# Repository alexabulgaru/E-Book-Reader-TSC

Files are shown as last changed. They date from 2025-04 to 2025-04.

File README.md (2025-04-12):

# E-Book-Reader-TSC - Bulgaru Alexandra 331CD

## Diagrama bloc

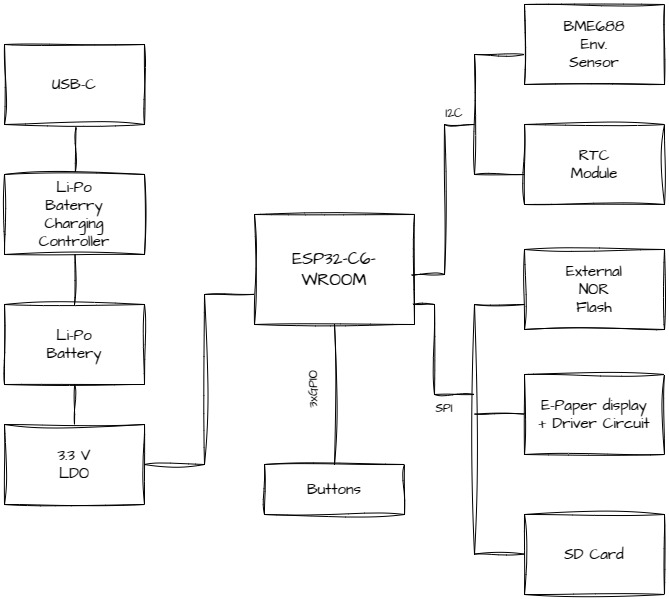
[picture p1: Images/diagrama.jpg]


## Bill Of Materials (BOM)
| Componenta | Achizitie | Datasheet |
| --- | --- | --- |
| PFMF.050.1 | [Cumpara](https://ro.mouser.com/ProductDetail/Schurter/PFMF.050.2?qs=1auRipcfynCums5v1iucSA%3D%3D) |  [Datasheet](https://ro.mouser.com/datasheet/2/358/typ_PFMF-1275918.pdf) |
| USB4110-GF-A | [Cumpara](https://ro.mouser.com/ProductDetail/GCT/USB4110-GF-A?qs=KUoIvG%2F9IlYiZvIXQjyJeA%3D%3D) | [Datasheet](https://ro.mouser.com/datasheet/2/837/GCT_USB4110_Product_Drawing___20k_cycles-3455479.pdf) |
| USBLC6-2SC6Y | [Cumpara](https://ro.mouser.com/ProductDetail/STMicroelectronics/USBLC6-2SC6Y?qs=gNDSiZmRJS%2FOgDexvXkdow%3D%3D) | [Datasheet](https://ro.mouser.com/datasheet/2/389/usblc6_2sc6y-1852505.pdf) |
| SD0805S020S1R0 | [Cumpara](https://ro.mouser.com/ProductDetail/KYOCERA-AVX/SD0805S020S1R0?qs=jCA%252BPfw4LHbpkAoSnwrdjw%3D%3D) | [Datasheet](https://ro.mouser.com/datasheet/2/40/schottky-3165252.pdf) |
| DMG2305UX-7 | [Cumpara](https://ro.mouser.com/ProductDetail/Diodes-Incorporated/DMG2305UX-7?qs=L1DZKBg7t5F%2FNBHrjfxC%252Bg%3D%3D) | [Datasheet](https://www.diodes.com/assets/Datasheets/DMG2305UX.pdf) |
| XC6220A331MR-G | [Cumpara](https://ro.mouser.com/ProductDetail/Torex-Semiconductor/XC6220A331MR-G?qs=AsjdqWjXhJ8ZSWznL1J0gg%3D%3D) | [Datasheet](https://ro.mouser.com/datasheet/2/760/xc6220-3371556.pdf) |
| Condensator 100 uF TANT | [Cumpara](https://ro.mouser.com/ProductDetail/KYOCERA-AVX/TAJW107M010RNJ?qs=Wtp%252Bf%2FAeVqIH8v1VxV%252B1Rg%3D%3D) | [Datasheet](https://ro.mouser.com/datasheet/2/40/TAJ-3165264.pdf) |
| 112A-TAAR-R03_ATTEND | [Cumpara](https://www.digikey.ro/en/products/detail/attend-technology/112A-TAAR-R03/17633923) | [Datasheet](https://www.attend.com.tw/data/download/file/112A-TAAR-R03_Spec.pdf)
| ESP32-C6-WROOM-1-N8 | [Cumpara](https://ro.mouser.com/ProductDetail/Espressif-Systems/ESP32-C6-WROOM-1-N8?qs=8Wlm6%252BaMh8ST02Gmwp74cw%3D%3D) | [Datasheet](https://ro.mouser.com/datasheet/2/891/Espressif_ESP32_C6_WROOM_1__Datasheet_V0_1_PRELIMI-3239987.pdf) |
| MCP73831 | [Cumpara](https://ro.mouser.com/ProductDetail/Microchip-Technology/MCP73831T-2ACI-OT?qs=yUQqVecv4qvbBQBGbHx0Mw%3D%3D) | [Datasheet](https://ro.mouser.com/datasheet/2/268/MCP73831_Family_Data_Sheet_DS20001984H-3441711.pdf) |
| CHG_LED | [Cumpara](https://store.comet.srl.ro/Catalogue/Product/40478/) | [Datasheet](https://www.snapeda.com/parts/KP-1608SURCK/Kingbright/datasheet/) |
| SI1308EDL-T1-GE3 | [Cumpara](https://ro.mouser.com/ProductDetail/Vishay-Semiconductors/SI1308EDL-T1-GE3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) | [Datasheet](https://www.vishay.com/doc?63399) |
| MBR0530 | [Cumpara](https://ro.mouser.com/ProductDetail/Micro-Commercial-Components-MCC/MBR0530-T?qs=9VyI4qLX4NTSXkb9ynzJnA%3D%3D) | [Datasheet](https://ro.mouser.com/datasheet/2/258/mcc_mbr0520~mbr0560sod123-1179695.pdf) |
| Bobina | [Cumpara](https://ro.mouser.com/ProductDetail/Wurth-Elektronik/744043680?qs=PGXP4M47uW6VkZq%252BkzjrHA%3D%3D) | [Datasheet](https://www.we-online.com/components/products/datasheet/744043680.pdf) |
| FH34SRJ-24S-0.5SH_99_ | [Cumpara](https://ro.mouser.com/ProductDetail/Hirose-Connector/FH34SRJ-24S-0.5SH99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) | [Datasheet](https://ro.mouser.com/datasheet/2/185/FH34SRJ_24S_0_5SH_99__CL0580_1255_6_99_2DDrawing_0-1615044.pdf) |
| BME688 | [Cumpara](https://ro.mouser.com/ProductDetail/Bosch-Sensortec/BME688?qs=IS%252B4QmGtzzqQoVDscqwx3A%3D%3D) | [Datasheet](https://ro.mouser.com/datasheet/2/783/bst_bme688_fl000-2307034.pdf) |
| BD5229G-TR | [Cumpara](https://ro.mouser.com/ProductDetail/ROHM-Semiconductor/BD5229G-TR?qs=4kLU8WoGk0vvnhrrYwdszw%3D%3D) | [Datasheet](https://fscdn.rohm.com/en/products/databook/datasheet/ic/power/voltage_detector/bd52xxg-e.pdf) |
| Buton adaptat | [Cumpara](https://ro.mouser.com/ProductDetail/CK/KMR221GULCLFS?qs=u2NJ%252B70r0goBXaNk7IrU0Q%3D%3D) | [Datasheet](https://www.ckswitches.com/media/1479/kmr2.pdf) |
| MAX17048G+T10 | [Cumpara](https://ro.mouser.com/ProductDetail/Analog-Devices-Maxim-Integrated/MAX17048G%2bT10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) | [Datasheet](https://ro.mouser.com/datasheet/2/609/MAX17048_MAX17049-3469099.pdf) |
| W25Q512JVEIQ | [Cumpara](https://ro.mouser.com/ProductDetail/Winbond/W25Q512JVEIQ?qs=l7cgNqFNU1jw6svr3at6tA%3D%3D) | [Datasheet](https://ro.mouser.com/datasheet/2/949/Winbond_W25Q512JV_Datasheet-3240039.pdf) |
| PGB1010603MR | [Cumpara](https://ro.mouser.com/ProductDetail/Littelfuse/PGB1010603MRHF?qs=KvZd0dN2Zg%2FuIq6icj%252BGKA%3D%3D) | [Datasheet](https://www.littelfuse.com/media?itemid=8a337998-d54d-466b-be4e-dc5bcd1f9321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) |
| QWIIC_RIGHT_ANGLE | [Cumpara](https://ro.mouser.com/ProductDetail/GCT/USB4110-GF-A?qs=KUoIvG%2F9IlYiZvIXQjyJeA%3D%3D) | [Datasheet](https://ro.mouser.com/datasheet/2/837/GCT_USB4110_Product_Drawing___20k_cycles-3455479.pdf) |
| DS3231SN# | [Cumpara](https://ro.mouser.com/ProductDetail/Analog-Devices-Maxim-Integrated/DS3231SN?qs=ffX8NcjNb2RmKAb9wAk9Ug%3D%3D) | [Datasheet](https://ro.mouser.com/datasheet/2/609/DS3231-3421123.pdf) |
| CPH3225A C10_SUPERCAP | [Cumpara](https://ro.mouser.com/ProductDetail/Seiko-Semiconductors/CPH3225A?qs=3etwrb1wR%252BhUOph6lAO7eg%3D%3D) | [Datasheet](https://ro.mouser.com/datasheet/2/360/Seiko_Instruments_MicroBattery_E_20230330_2024Jan_-3561061.pdf) |
| Condensator 100nF | [Cumpara](https://ro.mouser.com/ProductDetail/KYOCERA-AVX/06033G104ZAT2A?qs=NXubJDmysXJMPmHfVo6Z%252BA%3D%3D) | [Datasheet](https://ro.mouser.com/datasheet/2/40/KGM_Y5V-3223189.pdf) |
| Condensator 4.7uF | [Cumpara](https://ro.mouser.com/ProductDetail/KYOCERA-AVX/0402ZD475MAT2A?qs=NBFAU1oqP4W4U2PCPHI0sg%3D%3D) | [Datasheet](https://ro.mouser.com/datasheet/2/40/cx5r_KGM-3223198.pdf) |
| Condensator 10uF | [Cumpara](https://ro.mouser.com/ProductDetail/Samsung-Electro-Mechanics/CL10A106KQ8NNNL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) | [Datasheet](https://ro.mouser.com/datasheet/2/585/MLCC-1837944.pdf) |
| Condensator 1uF/50V | [Cumpara](https://ro.mouser.com/ProductDetail/KYOCERA-AVX/06035D105MAT2A?qs=k4kUdCzLgS5%252BURKe1SOIeQ%3D%3D) | [Datasheet](https://ro.mouser.com/datasheet/2/40/cx5r_KGM-3223198.pdf) |
| Rezistenta 10K | [Cumpara](https://ro.mouser.com/ProductDetail/Vishay-Beyschlag/MCS0402MD1002BE000?qs=17u8i%2FzlE8%2F9BrAaXkMk1w%3D%3D) | [Datasheet](https://www.vishay.com/doc?28952) |
| Rezistenta 200 | [Cumpara](https://ro.mouser.com/ProductDetail/Vishay-Beyschlag/MCS0402MD2000BE100?qs=3SvaY9RawMJNVte4F12%252BZQ%3D%3D) | [Datasheet](https://www.vishay.com/doc?28952) |
| Rezistenta 100K | [Cumpara](https://ro.mouser.com/ProductDetail/Vishay-Beyschlag/MCT0603PD1003DP500?qs=5aG0NVq1C4wWAn8Ei3OpZA%3D%3D) | [Datasheet](https://www.vishay.com/doc?28916) |
| Rezistenta 2.2 | [Cumpara](https://ro.mouser.com/ProductDetail/SEI-Stackpole/RMCF0402FT2R20?qs=IPgv5n7u5QbBgyl0jwhwsA%3D%3D) | [Datasheet](https://ro.mouser.com/datasheet/2/385/SEI_RMCF_RMCP-3077565.pdf) |
| Rezistenta 5K1| [Cumpara](https://www.venkel.com/part/TFCR0603-16W-K-5690FT) | [Datasheet](https://data.venkel.com/documents/tfcr-series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.) |
| Rezistenta 2K | [Cumpara](https://ro.mouser.com/ProductDetail/Vishay-Beyschlag/MCS04020C2001FE000?qs=wTZ%2FFzl837YG0wIkZJJOwQ%3D%3D) | [Datasheet](https://www.vishay.com/doc?28705) |
| Rezistenta 0.47 | [Cumpara](https://ro.mouser.com/ProductDetail/SEI-Stackpole/CSR0402JKR470?qs=IPgv5n7u5QawIB6nBEt8wA%3D%3D) | [Datasheet](https://ro.mouser.com/datasheet/2/385/SEI_CSR_CSRN-3077593.pdf) |
| Rezistenta 15 | [Cumpara](https://ro.mouser.com/ProductDetail/YAGEO/RT0402FRE0715RL?qs=BXCcY9r%252B08DFFpLSkPOIqQ%3D%3D) | [Datasheet](https://ro.mouser.com/datasheet/2/447/PYu_RT_1_to_0_01_RoHS_L_15-3461507.pdf) |
| SJ | [Cumpara](https://grabcad.com/library/solder-jumpers-1) | [Datasheet](https://docs.rs-online.com/6fae/A700000010766261.pdf)

## Functionalitatea Hardware
#### Alimentare & Baterie:
USB-C furnizeaza 5 V, intra in controllerul de incarcare Li-Po si LDO-ul de 3.3 V. Acest 3.3 V alimenteaza microcontrolerul (ESP32-C6), senzorii si perifericele. Bateria Li-Po asigura functionarea cand nu este disponibila o sursa USB.

Microcontrolerul (ESP32-C6) ruleaza firmware-ul, se conecteaza la retea (Wi-Fi 6, BLE), citeste senzorii interni (BME688, DS3231) si scrie/afiseaza pe ecranul E-Paper. Poate salva date sau citi fisiere din memoria externa Flash NOR sau de pe cardul SD.

#### Senzori & RTC:
BME688 (temperatura, umiditate, presiune, compusi volatili) si DS3231 (timp real) sunt pe magistrala I2C, astfel incat datele sunt preluate usor si prelucrate.

#### Afisaj E-Paper:
Se actualizeaza prin magistrala SPI; microcontrolerul trimite datele necesare prin pinul EPD_CS (chip select), EPD_DC (command/data), EPD_RST, iar afisajul confirma starea prin EPD_BUSY.

#### Extensii:
Qwiic / Stemma QT ofera posibilitatea de a conecta senzori suplimentari pe magistrala I2C; exista si un slot SD.

## Pini ESP32-C6
| Nume | GPIO / Pin | Functie | Descriere |
|---|---|---|---|
| **3V3** | 3V3 | Sursa principala de 3.3V | Asigura alimentarea necesara functionarii ESP32-C6 si a componentelor logice de pe placa |
| **EN (Reset)**  | EN | Activare/Dezactivare microcontroler | Controleaza alimentarea interna a modulului ESP32-C6; un impuls LOW poate reseta intregul sistem |
| **USB_D-** | IO12 | Linia negativa pentru USB | Utilizata in transferul de date prin protocol USB 2.0, in pereche diferentiala cu USB_D+ |
| **USB_D+** | IO13 | Linia pozitiva pentru USB | Utilizata in transferul de date prin protocol USB 2.0, in pereche diferentiala cu USB_D- |
| **Buton Boot**  | IO9 | Intrare in modul bootloader | Se conecteaza la masa pentru a forta incarcarea bootloader-ului ESP32-C6 (flash/programare firmware) |
| **Buton Change**| IO15 | Comutare mod de operare | Poate fi configurat in firmware pentru a schimba starea aplicatiei sau diverse moduri de functionare |
| **TX (UART)** | TXD0 / GPIO16 | Emisie seriala (UART) | Trimite date catre un terminal serial sau adaptor USB-serial, folosit pentru debug sau comunicatie |
| **RX (UART)** | RXD0 / GPIO17 | Receptie seriala (UART) | Primeste date de la un terminal serial sau adaptor USB-serial, folosit pentru debug sau comunicatie |
| **SCK (SPI)** | IO6 | Ceas SPI pentru transfer de date | Genereaza impulsurile de sincronizare pentru toate dispozitivele conectate la magistrala SPI |
| **MOSI (SPI)**  | IO7 | Linie de date catre dispozitive SPI (Master Out)| Transmite informatii de la microcontroler catre NOR Flash, card SD si ecran E-Paper |
| **MISO (SPI)**  | IO2 | Linie de date de la dispozitive SPI (Master In) | Receptioneaza informatii de la card SD, E-Paper si alte periferice SPI |
| **FLASH_CS** | IO11 | Selectare chip pentru memoria NOR Flash | Activeaza NOR Flash atunci cand se lucreaza cu acesta pe magistrala SPI |
| **EPD_CS** | IO10 | Selectare chip pentru E-Paper | Activeaza modulul E-Paper pe magistrala SPI in timpul transferului de date |
| **EPD_DC** | IO5 | Diferentiere comanda/date pentru E-Paper | Indica daca informatia transmisa pe SPI reprezinta instructiuni de control sau date de afisare |
| **EPD_RST** | IO23 | Reset extern E-Paper | Permite repornirea hardware a modulului E-Paper in cazul in care este necesar |
| **EPD_BUSY** | IO3 | Semnal de ocupare E-Paper | Avertizeaza microcontrolerul ca E-Paper este in curs de actualizare si nu poate primi alte comenzi |
| **SDA (I2C)** | IO21 | Linie de date I2C | Utilizata pentru comunicatia bidirectionala cu RTC DS3231, senzor BME688 si conector Qwiic/Stemma QT |
| **SCL (I2C)** | IO22 | Linie de ceas I2C | Sincronizeaza toate transferurile de pe magistrala I2C, inclusiv cu RTC, senzori si module de extensie |
| **SS_SD** | IO4 | Chip Select pentru card SD (SPI) | Stabileste cand cardul SD este activ pe magistrala SPI, prevenind conflicte cu alte dispozitive |
| **I2C_PW** | IO19 | Control alimentare senzori I2C | Poate porni sau opri tensiunea pentru senzorii conectati la magistrala I2C, contribuind la economisirea energiei |
| **EPD_3V3_C** | IO20 | Alimentare 3.3V dedicata E-Paper | Linie separata de 3.3V pentru a alimenta in mod specific modulul E-Paper si pentru a asigura stabilitatea semnalelor |
| **32KHZ** | IO1 | Linie semnal 32 kHz | Frecventa de ceas folosita de modulul RTC sau alte circuite care necesita un clock de 32 kHz |
| **INT_RTC** | IO0 | Intrerupere de la RTC DS3231 | Poate trezi ESP32-C6 din mod sleep sau poate semnala evenimente programate in RTC |
| **RTC_RST** | IO18 | Reset extern RTC | Linie pentru resetarea manuala a ceasului de timp real in situatii speciale |

## Estimare consum

| Componenta | Consum Activ (aprox) | Consum Sleep (aprox) | Observatii |
|---|---|---|---|
| ESP32-C6 | ~80–100 mA (Wi-Fi) | ~10–20 µA (DeepSleep)| Principalul consumator; Wi-Fi creste semnificativ consumul in mod activ |
| Senzor BME688 | ~2 mA in masurare | <1 µA in standby | Majoritatea timpului poate fi oprit sau in standby |
| RTC DS3231 | ~150–200 µA | ~3 µA in mod backup  | Funcioneaza permanent, dar consuma relativ putin |
| NOR Flash (SPI)  | ~10–30 mA | ~1 µA (Deep PwrDown) | Activ doar la operatiile de citire/scriere |
| E-Paper Display  | ~20–50 mA la refresh | ~0 µA in pasiv | Odata afisat, nu mai consuma energie pentru mentinerea imaginii |
| LDO + pasive | ~10–50 µA | n/a | Curent de repaus al regulatorului si mici consumuri auxiliare (rezistente, LED-uri etc.) |

## Etape implementare
1. Schematic: Am creat schematicul pe baza schemei electrice furnizate. Am folosit biblioteca DeskAssitant si am rulat ERC pentru a verifica prezenta erorilor.

2. PCB:
- Din schematic am dat "switch to PCB" si am plasat componentele conform modelului. Am desenat placa potrivit dimensiunilor, adaugand si decuparile. Componentele principale erau destul de vizibile, condensatoarele si rezistenele le-am asezat in functie de proximitatea acestora din schematic fata de componentele mari.
-Am facut autorutare pe top si pe bottom cu 0.15 mm, apoi am modificat grosimile firelor de alimentare sa fie minim 0.30 mm.
- Am creat planurile de masa cu semnalul GND, ulterior adaugand si via stitching tot cu semnalul GND. Majoritatea via stitching-urilor le-am pozitionat in jurul antenei.

3. 3D: Am adaugat in schematic componentele 3D din [Component Search Engine](https://componentsearchengine.com). Le-am pozitionat apoi conform footprint-ului.

4. Update carcasa: Dupa ce am pozitionat placuta in carcasa, am modificat carcasa astfel incat sa se potriveasca mufele.

5. Am creat modelele 3D pentru carcasa si display conform schemelor si le-am asezat in carcasa.

## Erori/probleme intampinate
1. Am acceptat erorile de PCB de tipul SMD-Hole Board.

2. Am uitat sa verific schematicul cu ERC prima data si am rulat abia dupa ce am terminat de importat toate componentele 3D. Am observat o eroare, a trebuit sa refac o conexiune si am reluat procesul de rutare, planuri de masa si via stitching.

3. Am modificat butoanele sa se potriveasca pe footprint.

4. Cand am generat prima data placuta 3D, aveam o portiune din PCB incompleta pe care nu am vazut-o. Din acest motiv, placuta avea gauri. Am corectat si am facut iar planul de masa si via stitching.

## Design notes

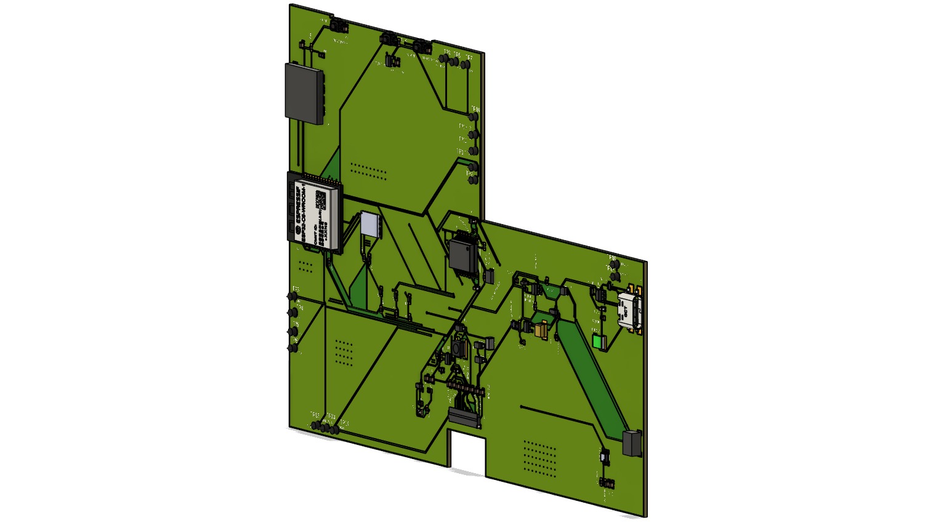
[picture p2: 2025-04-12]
Images/Placuta_2.jpeg

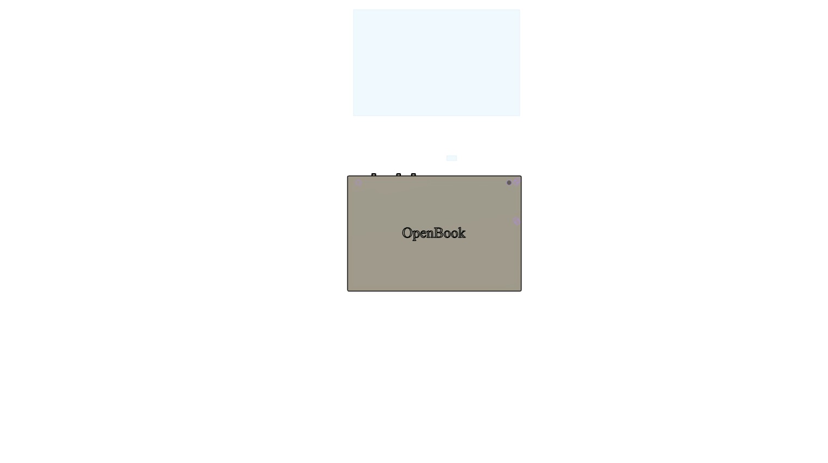
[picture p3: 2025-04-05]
Images/Carcasa_3.jpeg

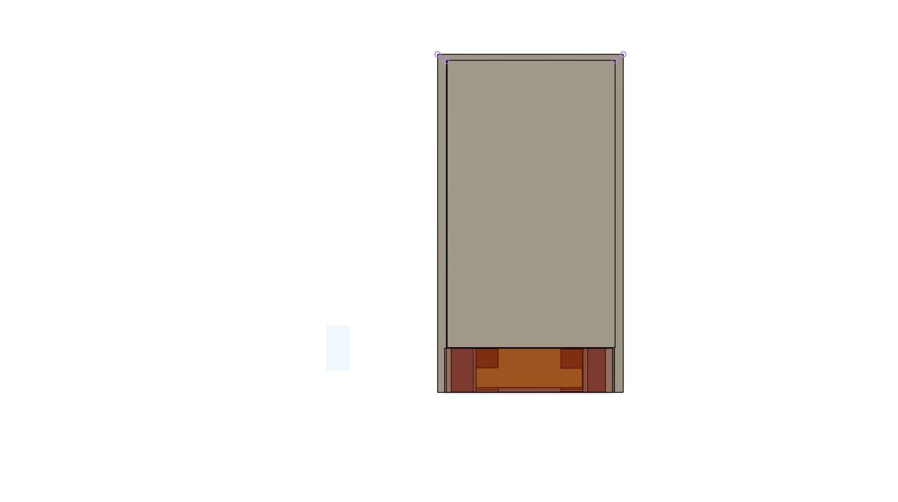
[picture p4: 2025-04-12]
Images/Baterie_3.jpeg

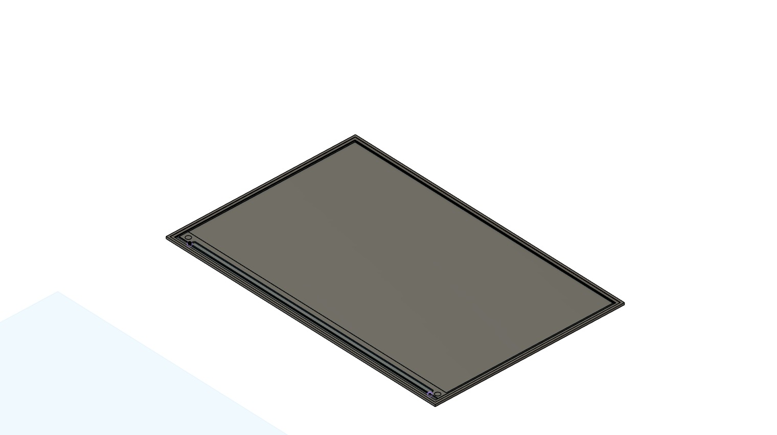
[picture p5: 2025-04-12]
Images/Display_1.jpeg

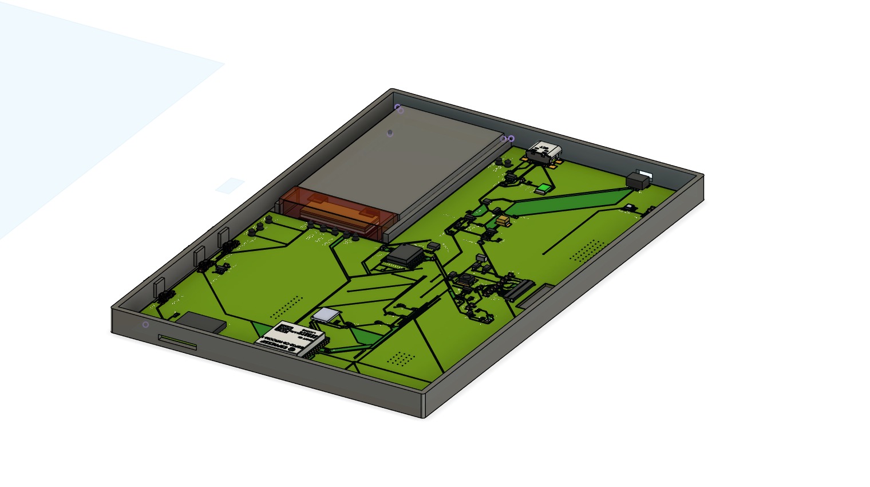
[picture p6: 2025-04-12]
Images/Dispozitiv_1.jpeg

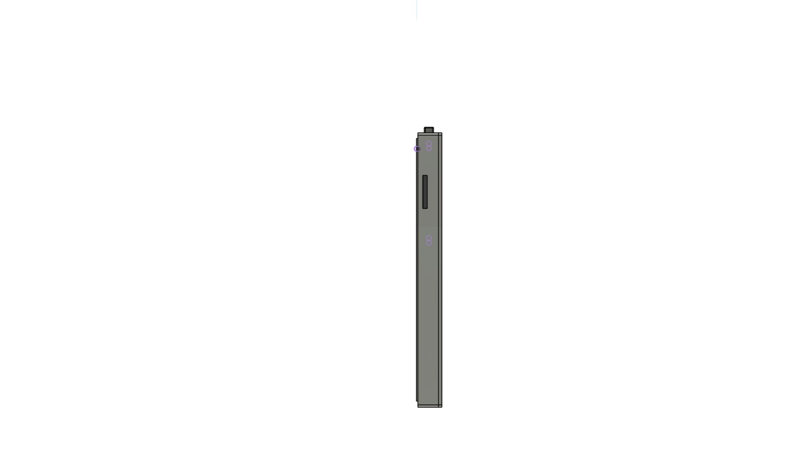
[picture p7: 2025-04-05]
Images/Carcasa_1.jpeg

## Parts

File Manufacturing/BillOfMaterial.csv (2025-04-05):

Qty | Value | Device | Package | Parts | Description | ARROW_PART_NUMBER | ARROW_PRICE-STOCK | AVAILABILITY | CENTROID_NOT_SPECIFIED | CHECK_PRICES | COPYRIGHT | DATASHEET | DESCRIPTION | DIGIKEY_DESCRIPTION | DIGIKEY_PART_NUMBER | HEIGHT | LEAD_FREE | MANUFACTURER_NAME | MANUFACTURER_PART_NUMBER | MF | MFR_NAME | MOUSER_PART_NUMBER | MOUSER_PRICE-STOCK | MOUSER_TESTING_PART_NUMBER | MOUSER_TESTING_PRICE-STOCK | MP | MPN | PACKAGE | POPULARITY | PREFIX | PRICE | PROD_ID | PURCHASE-URL | ROHS | SNAPEDA_LINK | SPICEMODEL | SPICEPREFIX | TEMPERATURE_RANGE_HIGH | TEMPERATURE_RANGE_LOW | TP_SIGNAL_NAME | VALUE
1 |  | ADAFRUIT_LEDCHIP-LED0603 | ADAFRUIT_CHIP-LED0603 | CHG_LED | LED
1 |  | SJ | SJ | SJ1 | SMD solder JUMPER |  |  |  |  |  |  |  |  |  |  |  |  |  |  |  |  |  |  |  |  |  |  |  | 3
1 | 0.1uF/50V | EAGLE-LTSPICE_CC0402 | EAGLE-LTSPICE_C0402 | EPD_C5 | CAPACITOR, European symbol |  |  |  |  |  |  |  |  |  |  |  |  |  |  |  |  |  |  |  |  |  |  |  |  |  |  |  |  |  |  | NONE | C
1 | 0.47 | ESP32_WROVER_EAGLE-LTSPICE_RR0402 | ESP32_WROVER_EAGLE-LTSPICE_R0402 | R3 | RESISTOR, European symbol |  |  |  |  |  |  |  |  |  |  |  |  |  |  |  |  |  |  |  |  |  |  |  |  |  |  |  |  |  |  | NONE | R
1 | 100K | ESP32_WROVER_EAGLE-LTSPICE_RR0402 | ESP32_WROVER_EAGLE-LTSPICE_R0402 | R1_PWRUSB | RESISTOR, European symbol |  |  |  |  |  |  |  |  |  |  |  |  |  |  |  |  |  |  |  |  |  |  |  |  |  |  |  |  |  |  | NONE | R
7 | 100nF | EAGLE-LTSPICE_CC0402 | EAGLE-LTSPICE_C0402 | C1, C2, C4_USB, C6, C8, C10, C_DELAY | CAPACITOR, European symbol |  |  |  |  |  |  |  |  |  |  |  |  |  |  |  |  |  |  |  |  |  |  |  |  |  |  |  |  |  |  | NONE | C
1 | 100nF | ESP32_WROVER_EAGLE-LTSPICE_CC0402 | ESP32_WROVER_EAGLE-LTSPICE_C0402 | C9 | CAPACITOR, European symbol |  |  |  |  |  |  |  |  |  |  |  |  |  |  |  |  |  |  |  |  |  |  |  |  |  |  |  |  |  |  | NONE | C
1 | 100uF TANT | RCL_CPOL-EUCT3528 | RCL_CT3528 | C3 | POLARIZED CAPACITOR, European symbol |  |  |  |  |  |  |  |  |  |  |  |  |  |  |  |  |  |  |  |  |  |  |  | 0 |  |  |  |  |  |  |  | C
16 | 10K | ESP32_WROVER_EAGLE-LTSPICE_RR0402 | ESP32_WROVER_EAGLE-LTSPICE_R0402 | R1, R1_PINH, R1_PINH1, R2-PINH, R2_PINH1, R4, R5, R6, R7, R8, R9, R10, R_BOOT, R_CHANGE, R_CL1, R_RESET | RESISTOR, European symbol |  |  |  |  |  |  |  |  |  |  |  |  |  |  |  |  |  |  |  |  |  |  |  |  |  |  |  |  |  |  | NONE | R
1 | 10uF | EAGLE-LTSPICE_CC0402 | EAGLE-LTSPICE_C0402 | C7 | CAPACITOR, European symbol |  |  |  |  |  |  |  |  |  |  |  |  |  |  |  |  |  |  |  |  |  |  |  |  |  |  |  |  |  |  | NONE | C
1 | 112A-TAAR-R03_ATTEND | 112A-TAAR-R03_ATTEND | 112ATAARR03ATTEND | J4 | Micro SD Card Socket, Push-Push Type, Top Mount, SMT, H=1.83mm, 10u |  |  |  |  |  |  |  | Micro SD Card Socket | Push-Push Type | Top Mount | SMT | H=1.83mm | 10u |  |  | 1.9mm |  | ATTEND | 112A-TAAR-R03 ATTEND
1 | 15 | ESP32_WROVER_EAGLE-LTSPICE_RR0402 | ESP32_WROVER_EAGLE-LTSPICE_R0402 | R_CAPACITOR | RESISTOR, European symbol |  |  |  |  |  |  |  |  |  |  |  |  |  |  |  |  |  |  |  |  |  |  |  |  |  |  |  |  |  |  | NONE | R
1 | 1uF | EAGLE-LTSPICE_CC0402 | EAGLE-LTSPICE_C0402 | C5 | CAPACITOR, European symbol |  |  |  |  |  |  |  |  |  |  |  |  |  |  |  |  |  |  |  |  |  |  |  |  |  |  |  |  |  |  | NONE | C
9 | 1uF/50V | EAGLE-LTSPICE_CC0402 | EAGLE-LTSPICE_C0402 | EPD_C1, EPD_C2, EPD_C6, EPD_C7, EPD_C8, EPD_C9, EPD_C10, EPD_C11, EPD_C12 | CAPACITOR, European symbol |  |  |  |  |  |  |  |  |  |  |  |  |  |  |  |  |  |  |  |  |  |  |  |  |  |  |  |  |  |  | NONE | C
1 | 2.2 | ESP32_WROVER_EAGLE-LTSPICE_RR0402 | ESP32_WROVER_EAGLE-LTSPICE_R0402 | R2 | RESISTOR, European symbol |  |  |  |  |  |  |  |  |  |  |  |  |  |  |  |  |  |  |  |  |  |  |  |  |  |  |  |  |  |  | NONE | R
1 | 200 | ESP32_WROVER_EAGLE-LTSPICE_RR0402 | ESP32_WROVER_EAGLE-LTSPICE_R0402 | R1_BAT | RESISTOR, European symbol |  |  |  |  |  |  |  |  |  |  |  |  |  |  |  |  |  |  |  |  |  |  |  |  |  |  |  |  |  |  | NONE | R
2 | 20V/4.2A/52mO/1.4W | ESP32_WROVER_SPARKFUN-DISCRETESEMI_MOSFET_PCH-DMG2305UX-7 | ESP32_WROVER_SPARKFUN-DISCRETESEMI_SOT23-3 | Q1, Q2 | P-channel MOSFETs |  |  |  |  |  |  |  |  |  |  |  |  |  |  |  |  |  |  |  |  |  |  |  |  |  |  | TRAN-14388 |  |  |  |  |  |  |  |  | 20V/4.2A/52mO/1.4W
1 | 2K | ESP32_WROVER_EAGLE-LTSPICE_RR0402 | ESP32_WROVER_EAGLE-LTSPICE_R0402 | R2_BAT | RESISTOR, European symbol |  |  |  |  |  |  |  |  |  |  |  |  |  |  |  |  |  |  |  |  |  |  |  |  |  |  |  |  |  |  | NONE | R
4 | 4.7uF | EAGLE-LTSPICE_CC0402 | EAGLE-LTSPICE_C0402 | C1_BAT, C1_BAT1, C1_BAT2, C2_BAT | CAPACITOR, European symbol |  |  |  |  |  |  |  |  |  |  |  |  |  |  |  |  |  |  |  |  |  |  |  |  |  |  |  |  |  |  | NONE | C
1 | 4.7uF/25V | EAGLE-LTSPICE_CC0402 | EAGLE-LTSPICE_C0402 | C4 | CAPACITOR, European symbol |  |  |  |  |  |  |  |  |  |  |  |  |  |  |  |  |  |  |  |  |  |  |  |  |  |  |  |  |  |  | NONE | C
1 | 4.7uf | EAGLE-LTSPICE_CC0402 | EAGLE-LTSPICE_C0402 | C5_USB | CAPACITOR, European symbol |  |  |  |  |  |  |  |  |  |  |  |  |  |  |  |  |  |  |  |  |  |  |  |  |  |  |  |  |  |  | NONE | C
2 | 5k1 | ESP32_WROVER_EAGLE-LTSPICE_RR0402 | ESP32_WROVER_EAGLE-LTSPICE_R0402 | R2-USB, R2-USB1 | RESISTOR, European symbol |  |  |  |  |  |  |  |  |  |  |  |  |  |  |  |  |  |  |  |  |  |  |  |  |  |  |  |  |  |  | NONE | R
1 | 68uH | 744043680IND_4828-WE-TPC_WRE | IND_4828-WE-TPC_WRE | L1 |  |  |  |  |  |  | Copyright (C) 2024 Ultra Librarian. All rights reserved. |  |  |  |  |  |  |  | 744043680 |  | Wurth Electronics
1 | BD5229G-TR | BD5229G-TR | SOT95P280X125-5N | IC2 | Voltage Detector with Adjustable Delay Time: CMOS processes are utilized to develop high precision, low current consumption CMOS reset ICs that allow arbitrary setting of the delay time. The extensive lineup includes both Nch Open Drain and CMOS output types in a wide range of detection voltages (from 2.3V to 6.0V, in 0.1V steps), enabling selection of the ideal solution based on customer requirements. In addition, the entire series is of course both lead-free and RoHS-compliant. |  |  |  |  |  |  |  | Voltage Detector with Adjustable Delay Time: CMOS processes are utilized to develop high precision | low current consumption CMOS reset ICs that allow arbitrary setting of the delay time. The extensive lineup includes both Nch Open Drain and CMOS output types in a wide range of detection voltages (from 2.3V to 6.0V | in 0.1V steps) | enabling selection of the ideal solution based on customer requirements. In addition | the entire series is of course both lead-free and RoHS-compliant. |  |  | 1.25mm |  | ROHM Semiconductor | BD5229G-TR |  |  | 755-BD5229G-TR | https://www.mouser.co.uk/ProductDetail/ROHM-Semiconductor/BD5229G-TR?qs=4kLU8WoGk0vvnhrrYwdszw%3D%3D
1 | BME688 | ESP32_WROVER_BME680_BME680 | ESP32_WROVER_BME680_PSON80P300X300X100-8N | SENSOR2 | Integrated Environmental Unit |  |  | Unavailable |  |  |  |  | Integrated Environmental Unit |  |  |  |  |  |  | Bosch Sensortec |  |  |  |  |  | BME680 |  | LGA-8 Bosch Tools |  |  | None
3 | BUTTON_CUSYOMV1 | BUTTON_CUSYOMV1 | MYBUTTON | BOOT_BUTTON, CHANGE_BUTTON, RESET_BUTTON
1 | CPH3225A | CPH3225A | CAPCP3225X100N | C10_SUPERCAP | Cap 0.011F 3.3V 1210 Flat Check availability |  |  | Not in stock |  | https://www.snapeda.com/parts/CPH3225A/Seiko+Instruments/view-part/?ref=eda |  |  | 11 mF (EDLC) Supercapacitor 3.3 V 1210 (3225 Metric) - - |  |  |  |  |  |  | Seiko Instruments |  |  |  |  |  | CPH3225A |  | 1210 Seiko |  |  | None |  | https://www.snapeda.com/api/url_track_click_mouser/?unipart_id=562593&manufacturer=Seiko Instruments&part_name=CPH3225A&search_term=None |  | https://www.snapeda.com/parts/CPH3225A/Seiko+Instruments/view-part/?ref=snap
1 | DS3231SN# | DS3231SN# | SOIC127P1032X265-16N | U3 | Real Time Clock Serial 16-Pin SOIC W T/R Check availability |  |  | In Stock |  | https://www.snapeda.com/parts/DS3231SN%23/Analog+Devices/view-part/?ref=eda |  |  | Extremely Accurate I²C-Integrated RTC/TCXO/Crystal |  |  |  |  |  |  | Analog Devices |  |  |  |  |  | DS3231SN# |  | SOIC-16 Maxim |  |  | None |  | https://www.snapeda.com/api/url_track_click_mouser/?unipart_id=99048&manufacturer=Analog Devices&part_name=DS3231SN#&search_term=None |  | https://www.snapeda.com/parts/DS3231SN%23/Analog+Devices/view-part/?ref=snap
1 | ESP32-C6-WROOM-1-N8 | ESP32-C6-WROOM-1-N8 | XCVR_ESP32-C6-WROOM-1-N8 | U2 | Check availability |  |  | In Stock |  | https://www.snapeda.com/parts/ESP32-C6-WROOM-1-N8/Espressif+Systems/view-part/?ref=eda |  |  | Multiprotocol Modules ESP32-C6 module | Wi-Fi 6 in 2.4 GHz band | Bluetooth 5 | Zigbee 3.0 and Thread. ESP34-WROOM Compatible - ENGINEERING SAMPLE |  |  |  |  |  |  | Espressif Systems |  |  |  |  |  | ESP32-C6-WROOM-1-N8 |  | None |  |  | None |  |  |  | https://www.snapeda.com/parts/ESP32-C6-WROOM-1-N8/Espressif+Systems/view-part/?ref=snap
1 | ESP32C6_VARISTORCN1812 | ESP32C6_VARISTORCN1812 | ESP32C6_VARISTOR_CT/CN1812 | PFMF.050.1 | VARISTOR |  |  |  |  |  |  |  |  |  |  |  |  |  |  |  |  |  |  |  |  |  |  |  | 0
2 | ESP32_WROVER_AVX---SD0805S020S1R0_AVX_SD0805S020S1R0_0_0AVX_SD0805S020S1R0_0_0 | ESP32_WROVER_AVX---SD0805S020S1R0_AVX_SD0805S020S1R0_0_0AVX_SD0805S020S1R0_0_0 | ESP32_WROVER_AVX---SD0805S020S1R0_AVX_SD0805S020S1R0_0 | D2, D7 | Schottky Barrier Rectifier Diode |  |  |  | No |  |  | http://datasheets.avx.com/schottky.pdf |  | DIODE SCHOTTKY 20V 1A 0805 | 478-7800-1-ND |  | yes |  |  | AVX |  | 581-SD0805S020S1R0 |  |  |  |  |  | 0805 (2012 metric) |  | D |  |  |  | yes |  |  |  | +125°C | -55°C
1 | ESP32_WROVER_SPARKFUN-IC-POWER_MCP73831 | ESP32_WROVER_SPARKFUN-IC-POWER_MCP73831 | ESP32_WROVER_SPARKFUN-IC-POWER_SOT23-5 | MCP73831 | MCP73831T Li-Ion, Li-Pol Controller |  |  |  |  |  |  |  |  |  |  |  |  |  |  |  |  |  |  |  |  |  |  |  |  |  |  | IC-09995
1 | FH34SRJ-24S-0.5SH_99_ | FH34SRJ-24S-0.5SH_99_ | FH34SRJ24S05SH99 | J1 | (0.50mm) Surface Mount, Right Angle |  |  |  |  |  |  |  | 24 Position FFC | FPC Connector Contacts | (0.50mm) Surface Mount | Right Angle |  |  | 1.1mm |  | Hirose | FH34SRJ-24S-0.5SH(99) |  |  | 798-FH34SRJ24S05SH99 | https://www.mouser.co.uk/ProductDetail/Hirose-Connector/FH34SRJ-24S-0.5SH99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
1 | MAX17048G+T10 | MAX17048G+T10 | SON50P200X200X80-9N | U4 | Check availability |  |  | In Stock |  | https://www.snapeda.com/parts/MAX17048G+T10/Analog+Devices/view-part/?ref=eda |  |  | 3µA 1-Cell/2-Cell Fuel Gauge with ModelGauge |  |  |  |  |  |  | Analog Devices |  |  |  |  |  | MAX17048G+T10 |  | TDFN-8 Maxim |  |  | None |  | https://www.snapeda.com/api/url_track_click_mouser/?unipart_id=329239&manufacturer=Analog Devices&part_name=MAX17048G+T10&search_term=None |  | https://www.snapeda.com/parts/MAX17048G+T10/Analog+Devices/view-part/?ref=snap
3 | MBR0530 | MBR0530 | SOD3716X135N | D3, D4, D5 | ON SEMICONDUCTOR - MBR0530 - DIODE, SCHOTTKY, 0.5A, 30V, SOD-123 |  |  | In Stock |  | https://www.snapeda.com/parts/MBR0530/Onsemi/view-part/?ref=eda |  |  | Diode Schottky 30 V 500mA Surface Mount SOD-123 |  |  |  |  |  |  | ON Semiconductor |  |  |  |  |  | MBR0530 |  | SOD-123-2 ON Semiconductor |  |  | None |  | https://www.snapeda.com/api/url_track_click_mouser/?unipart_id=179458&manufacturer=ON Semiconductor&part_name=MBR0530&search_term=None |  | https://www.snapeda.com/parts/MBR0530/Onsemi/view-part/?ref=snap
6 | PGB1010603MR | PGB1010603MR | DIOC1608X36N | D6, D8, D9, D10, D11, D12 | Check availability |  |  | In Stock |  | https://www.snapeda.com/parts/PGB1010603MR/Littelfuse/view-part/?ref=eda |  |  | 150V (Typ) Clamp - Ipp Tvs Diode Surface Mount 0603 (1608 Metric) |  |  |  |  |  |  | Littelfuse Inc. |  |  |  |  |  | PGB1010603MR |  | 0603 Littelfuse Inc. |  |  | None |  | https://www.snapeda.com/api/url_track_click_mouser/?unipart_id=5659453&manufacturer=Littelfuse Inc.&part_name=PGB1010603MR&search_term=None |  | https://www.snapeda.com/parts/PGB1010603MR/Littelfuse/view-part/?ref=snap
1 | QWIIC_RIGHT_ANGLE | QWIIC_CONNECTORJS-1MM | JST04_1MM_RA | J3 | SparkFun I2C Standard Qwiic Connector |  |  |  |  |  |  |  |  |  |  |  |  |  |  |  |  |  |  |  |  |  |  |  |  |  |  | CONN-13694 |  |  |  |  |  |  |  |  | QWIIC_RIGHT_ANGLE
1 | SAMACSYS_PARTS_USB4110-GF-A | SAMACSYS_PARTS_USB4110-GF-A | SAMACSYS_PARTS_USB4110GFA | J2 | CONN USB 2.0 TYPE-C R/A SMT |  |  |  |  |  |  |  | CONN USB 2.0 TYPE-C R/A SMT |  |  | 3.26mm |  | GCT (GLOBAL CONNECTOR TECHNOLOGY) | USB4110-GF-A |  |  | 640-USB4110-GF-A | https://www.mouser.co.uk/ProductDetail/GCT/USB4110-GF-A?qs=KUoIvG%2F9IlYiZvIXQjyJeA%3D%3D
1 | SI1308EDL-T1-GE3 | SI1308EDL-T1-GE3 | SOT65P210X110-3N | Q3 | MOSFET N-Ch 30V 1.5A TrenchFET SC70 Vishay Si1308EDL-T1-GE3 N-channel MOSFET Transistor, 1.5 A, 30 V, 3-Pin SC-70 |  |  | In Stock |  | https://www.snapeda.com/parts/SI1308EDL-T1-GE3/Vishay+Siliconix/view-part/?ref=eda |  |  | Si1308EDL-T1-GE3 N-channel MOSFET Transistor | 1.5 A | 30 V | 3-Pin SC-70 | Siliconix / Vishay SI1308EDL-T1-GE3 |  |  |  |  |  |  | Vishay Siliconix |  |  |  |  |  | SI1308EDL-T1-GE3 |  | SOT-323 Vishay Semiconductor |  |  | None |  | https://www.snapeda.com/api/url_track_click_mouser/?unipart_id=274603&manufacturer=Vishay Siliconix&part_name=SI1308EDL-T1-GE3&search_term=None |  | https://www.snapeda.com/parts/SI1308EDL-T1-GE3/Vishay+Siliconix/view-part/?ref=snap
17 | TPTP20R | TPTP20R | TP20R | TP1, TP2, TP3, TP4, TP5, TP6, TP7, TP8, TP9, TP10, TP11, TP12, TP13, TP14, TP15, TP16, TP17 | Test pad |  |  |  |  |  |  |  |  |  |  |  |  |  |  |  |  |  |  |  |  |  |  |  | 2
1 | USBLC6-2SC6Y | USBLC6-2SC6Y | SOT95P280X145-6N | D1 | Low Cap. ESD Protection Auto SOT-23-6 STMicroelectronics USBLC6-2SC6Y, Dual Uni-Directional TVS Diode Array, 6-Pin SOT-23 |  |  | In Stock |  | https://www.snapeda.com/parts/USBLC6-2SC6Y/STMicroelectronics/view-part/?ref=eda |  |  | 17V Clamp 5A (8/20µs) Ipp Tvs Diode Surface Mount SOT-23-6 |  |  |  |  |  |  | STMicroelectronics |  |  |  |  |  | USBLC6-2SC6Y |  | SOT-23-6 STMicroelectronics |  |  | None |  |  |  | https://www.snapeda.com/parts/USBLC6-2SC6Y/STMicroelectronics/view-part/?ref=snap
1 | W25Q512JVEIQ | W25Q512JVEIQ | SON127P600X800X80-9N | U1 | Check availability |  |  | In Stock |  | https://www.snapeda.com/parts/W25Q512JVEIQ/Winbond+Electronics/view-part/?ref=eda |  |  | FLASH - NOR Memory IC 512Mb (64M x 8) SPI - Quad I/O 133 MHz 8-WSON (8x6) |  |  |  |  |  |  | Winbond Electronics |  |  |  |  |  | W25Q512JVEIQ |  | Package |  |  | None |  |  |  | https://www.snapeda.com/parts/W25Q512JVEIQ/Winbond+Electronics/view-part/?ref=snap
1 | XC6220A331MR-G | XC6220A331MR-G | SOT95P280X120-5N | IC4 | LDO Voltage Regulators |  |  |  |  |  |  |  | LDO Voltage Regulators |  |  | 1.2mm |  | Torex | XC6220A331MR-G |  |  | 865-XC6220A331MR-G | https://www.mouser.co.uk/ProductDetail/Torex-Semiconductor/XC6220A331MR-G?qs=AsjdqWjXhJ8ZSWznL1J0gg%3D%3D

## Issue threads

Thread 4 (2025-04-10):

Warning Labels

dariusbbl, 2025-04-10:
Am observat niste warning-uri la Schematic in ceea ce priveste label-urile PREVGL si PREVGH , intrucat ele apar doar in zona de E-Paper Drive Circuit, nu exista si in  E-Paper Display (ar trebui sa apara de 2 ori fiecare, pe schematic sunt doar 1 data).

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

Closed 2025-04-11.

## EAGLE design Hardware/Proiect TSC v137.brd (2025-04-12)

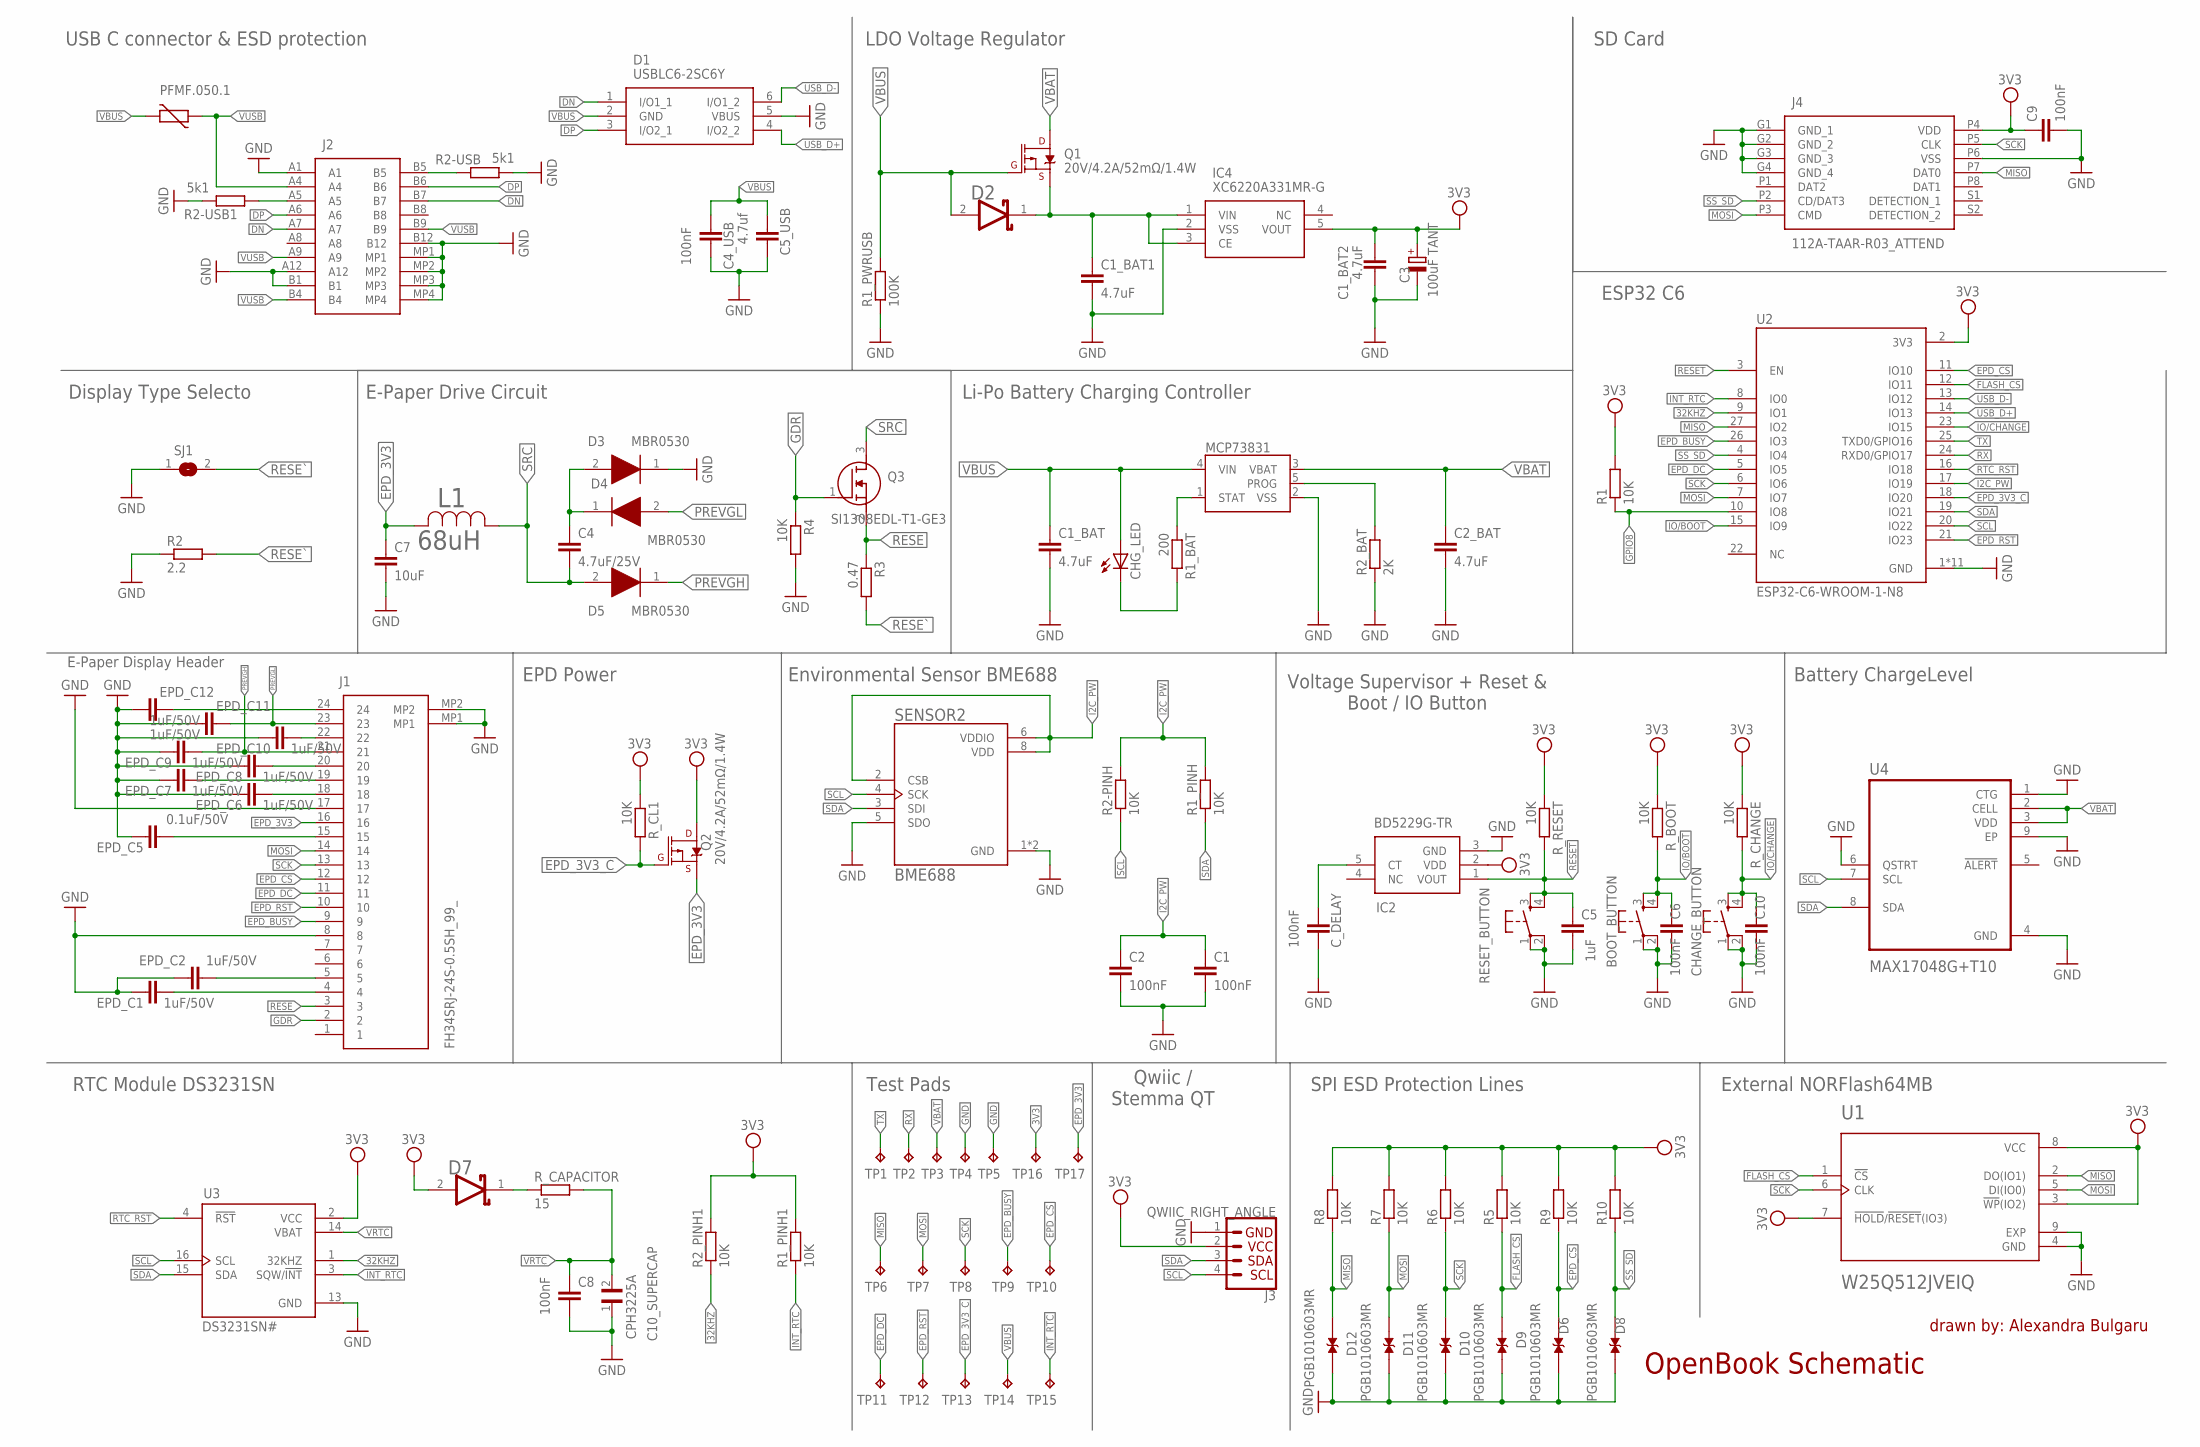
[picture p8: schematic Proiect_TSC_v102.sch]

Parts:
BOOT_BUTTON: BUTTON_CUSYOMV1; MYBUTTON
C1, C2, C4_USB, C6, C8, C10: 100nF; EAGLE-LTSPICE_C0402
C1_BAT, C1_BAT1, C1_BAT2, C2_BAT: 4.7uF; EAGLE-LTSPICE_C0402
C3: 100uF TANT; RCL_CT3528
C4: 4.7uF/25V; EAGLE-LTSPICE_C0402
C5: 1uF; EAGLE-LTSPICE_C0402
C5_USB: 4.7uf; EAGLE-LTSPICE_C0402
C7: 10uF; EAGLE-LTSPICE_C0402
C9: 100nF; ESP32_WROVER_EAGLE-LTSPICE_C0402
C10_SUPERCAP: CPH3225A; CAPCP3225X100N
CHANGE_BUTTON: BUTTON_CUSYOMV1; MYBUTTON
CHG_LED: ADAFRUIT_LEDCHIP-LED0603; ADAFRUIT_CHIP-LED0603
C_DELAY: 100nF; EAGLE-LTSPICE_C0402
D1: USBLC6-2SC6Y; SOT95P280X145-6N
D2, D7: ESP32_WROVER_AVX---SD0805S020S1R0_AVX_SD0805S020S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; ESP32_WROVER_AVX---SD0805S020S1R0_AVX_SD0805S020S1R0_0
D3, D4, D5: MBR0530; SOD3716X135N
D6, D8, D9, D10, D11, D12: PGB1010603MR; DIOC1608X36N
EPD_C1, EPD_C2, EPD_C6, EPD_C7, EPD_C8, EPD_C9, EPD_C10, EPD_C11, EPD_C12: 1uF/50V; EAGLE-LTSPICE_C0402
EPD_C5: 0.1uF/50V; EAGLE-LTSPICE_C0402
IC2: BD5229G-TR; SOT95P280X125-5N
IC4: XC6220A331MR-G; SOT95P280X120-5N
J1: FH34SRJ-24S-0.5SH_99_; FH34SRJ24S05SH99
J2: SAMACSYS_PARTS_USB4110-GF-A; SAMACSYS_PARTS_USB4110GFA
J3: QWIIC_RIGHT_ANGLE; JST04_1MM_RA
J4: 112A-TAAR-R03_ATTEND; 112ATAARR03ATTEND
L1: 68uH; IND_4828-WE-TPC_WRE
MCP73831: ESP32_WROVER_SPARKFUN-IC-POWER_MCP73831; ESP32_WROVER_SPARKFUN-IC-POWER_SOT23-5
PFMF.050.1: ESP32C6_VARISTORCN1812; ESP32C6_VARISTOR_CT/CN1812
Q1, Q2: 20V/4.2A/52mΩ/1.4W; ESP32_WROVER_SPARKFUN-DISCRETESEMI_SOT23-3
Q3: SI1308EDL-T1-GE3; SOT65P210X110-3N
R1, R1_PINH, R1_PINH1, R2-PINH, R2_PINH1, R4, R5, R6, R7, R8, R9, R10: 10K; ESP32_WROVER_EAGLE-LTSPICE_R0402
R1_BAT: 200; ESP32_WROVER_EAGLE-LTSPICE_R0402
R1_PWRUSB: 100K; ESP32_WROVER_EAGLE-LTSPICE_R0402
R2: 2.2; ESP32_WROVER_EAGLE-LTSPICE_R0402
R2-USB, R2-USB1: 5k1; ESP32_WROVER_EAGLE-LTSPICE_R0402
R2_BAT: 2K; ESP32_WROVER_EAGLE-LTSPICE_R0402
R3: 0.47; ESP32_WROVER_EAGLE-LTSPICE_R0402
RESET_BUTTON: BUTTON_CUSYOMV1; MYBUTTON
R_BOOT: 10K; ESP32_WROVER_EAGLE-LTSPICE_R0402
R_CAPACITOR: 15; ESP32_WROVER_EAGLE-LTSPICE_R0402
R_CHANGE: 10K; ESP32_WROVER_EAGLE-LTSPICE_R0402
R_CL1: 10K; ESP32_WROVER_EAGLE-LTSPICE_R0402
R_RESET: 10K; ESP32_WROVER_EAGLE-LTSPICE_R0402
SENSOR2: BME688; ESP32_WROVER_BME680_PSON80P300X300X100-8N
SJ1: SJ
TP1, TP2, TP3, TP4, TP5, TP6, TP7, TP8, TP9, TP10, TP11, TP12, TP13, TP14, TP15, TP16, TP17: TPTP20R; TP20R
U1: W25Q512JVEIQ; SON127P600X800X80-9N
U2: ESP32-C6-WROOM-1-N8; XCVR_ESP32-C6-WROOM-1-N8
U3: DS3231SN#; SOIC127P1032X265-16N
U4: MAX17048G+T10; SON50P200X200X80-9N

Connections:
3V3: C1_BAT2.2, C3.+, C9.1, D7.2 (ANODE), IC2.2 (VDD), IC4.5 (VOUT), J3.2, J4.P4 (VDD), Q2.3 (D), R1.2, R1_PINH1.2, R2_PINH1.2, R5.2, R6.2, R7.2, R8.2, R9.2, R10.2, R_BOOT.1, R_CHANGE.1, R_CL1.1, R_RESET.1, TP16.TP, U1.3 (!WP!(IO2)), U1.7 (!HOLD!/!RESET!(IO3)), U1.8 (VCC), U2.2 (3V3), U3.2 (VCC)
32KHZ: R2_PINH1.1, U2.9 (IO1), U3.1 (32KHZ)
DN: D1.1 (I/O1_1), J2.A7, J2.B7
DP: D1.3 (I/O2_1), J2.A6, J2.B6
EPD_3V3: C7.1, J1.16, L1.2, Q2.2 (S), TP17.TP
EPD_3V3_C: Q2.1 (G), R_CL1.2, TP13.TP, U2.18 (IO20)
EPD_BUSY: J1.9, TP9.TP, U2.26 (IO3)
EPD_CS: D6.1, J1.12, R9.1, TP10.TP, U2.11 (IO10)
EPD_DC: J1.11, TP11.TP, U2.5 (IO5)
EPD_RST: J1.10, TP12.TP, U2.21 (IO23)
FLASH_CS: D9.1, R5.1, U1.1 (!CS), U2.12 (IO11)
GDR: J1.2, Q3.1 (G), R4.1
GND: BOOT_BUTTON.1, BOOT_BUTTON.2, C1.2, C1_BAT.2, C1_BAT1.2, C1_BAT2.1, C2.2, C2_BAT.2, C3.-, C4_USB.2, C5.2, C5_USB.2, C6.2, C7.2, C8.2, C9.2, C10.2, C10_SUPERCAP.1, CHANGE_BUTTON.1, CHANGE_BUTTON.2, C_DELAY.2, D1.5 (VBUS), D3.1 (K), D6.2, D8.2, D9.2, D10.2, D11.2, D12.2, EPD_C1.1, EPD_C2.1, EPD_C5.1, EPD_C6.1, EPD_C7.1, EPD_C8.1, EPD_C9.1, EPD_C10.1, EPD_C11.1, EPD_C12.1, IC2.3 (GND), IC4.2 (VSS), J1.8, J1.17, J1.MP1, J1.MP2, J2.A1, J2.A12, J2.B1, J2.B12, J2.MP1, J2.MP2, J2.MP3, J2.MP4, J3.1, J4.G1 (GND_1), J4.G2 (GND_2), J4.G3 (GND_3), J4.G4 (GND_4), J4.P6 (VSS), MCP73831.2 (VSS), R1_PWRUSB.1, R2.1, R2-USB.2, R2-USB1.2, R2_BAT.1, R4.2, RESET_BUTTON.1, RESET_BUTTON.2, SENSOR2.1 (GND), SENSOR2.5 (SDO), SENSOR2.7 (GND), SJ1.1, TP4.TP, TP5.TP, U1.4 (GND), U1.9 (EXP), U2.1 (GND), U2.28 (GND), U2.29_1 (GND), U2.29_2 (GND), U2.29_3 (GND), U2.29_4 (GND), U2.29_5 (GND), U2.29_6 (GND), U2.29_7 (GND), U2.29_8 (GND), U2.29_9 (GND), U3.13 (GND), U4.1 (CTG), U4.4 (GND), U4.6 (QSTRT), U4.9 (EP)
GPIO8: R1.1, U2.10 (IO8)
I2C_PW: C1.1, C2.1, R1_PINH.2, R2-PINH.2, SENSOR2.2 (CSB), SENSOR2.6 (VDDIO), SENSOR2.8 (VDD), U2.17 (IO19)
INT_RTC: R1_PINH1.1, TP15.TP, U2.8 (IO0), U3.3 (SQW/!INT)
IO/BOOT: BOOT_BUTTON.3, BOOT_BUTTON.4, C6.1, R_BOOT.2, U2.15 (IO9)
IO/CHANGE: C10.1, CHANGE_BUTTON.3, CHANGE_BUTTON.4, R_CHANGE.2, U2.23 (IO15)
MISO: D12.1, J4.P7 (DAT0), R8.1, TP6.TP, U1.2 (DO(IO1)), U2.27 (IO2)
MOSI: D11.1, J1.14, J4.P3 (CMD), R7.1, TP7.TP, U1.5 (DI(IO0)), U2.7 (IO7)
unnamed: J2.B5, R2-USB.1
unnamed: J2.A5, R2-USB1.1
unnamed: C1_BAT1.1, D2.1 (CATHODE), IC4.1 (VIN), IC4.3 (CE), Q1.2 (S)
unnamed: MCP73831.1 (STAT), R1_BAT.1
unnamed: C4.1, D3.2 (A), D4.1 (K)
unnamed: CHG_LED.C, R1_BAT.2
unnamed: MCP73831.5 (PROG), R2_BAT.2
unnamed: EPD_C1.2, J1.4
unnamed: EPD_C2.2, J1.5
unnamed: EPD_C5.2, J1.15
unnamed: EPD_C6.2, J1.18
unnamed: EPD_C7.2, J1.19
unnamed: EPD_C8.2, J1.20
unnamed: EPD_C10.2, J1.22
unnamed: C_DELAY.1, IC2.5 (CT)
unnamed: D7.1 (CATHODE), R_CAPACITOR.1
unnamed: EPD_C12.2, J1.24
PREVGH: D5.1 (K), EPD_C9.2, J1.21
PREVGL: D4.2 (A), EPD_C11.2, J1.23
RESE: J1.3, Q3.2 (S), R3.1
RESET: C5.1, IC2.1 (VOUT), RESET_BUTTON.3, RESET_BUTTON.4, R_RESET.2, U2.3 (EN)
RESE`: R2.2, R3.2, SJ1.2
RTC_RST: U2.16 (IO18), U3.4 (!RST)
RX: TP2.TP, U2.24 (RXD0/GPIO17)
SCK: D10.1, J1.13, J4.P5 (CLK), R6.1, TP8.TP, U1.6 (CLK), U2.6 (IO6)
SCL: J3.4, R2-PINH.1, SENSOR2.4 (SCK), U2.20 (IO22), U3.16 (SCL), U4.7 (SCL)
SDA: J3.3, R1_PINH.1, SENSOR2.3 (SDI), U2.19 (IO21), U3.15 (SDA), U4.8 (SDA)
SRC: C4.2, D5.2 (A), L1.1, Q3.3 (D)
SS_SD: D8.1, J4.P2 (CD/DAT3), R10.1, U2.4 (IO4)
TX: TP1.TP, U2.25 (TXD0/GPIO16)
USB_D+: D1.4 (I/O2_2), U2.14 (IO13)
USB_D-: D1.6 (I/O1_2), U2.13 (IO12)
VBAT: C2_BAT.1, MCP73831.3 (VBAT), Q1.3 (D), TP3.TP, U4.2 (CELL), U4.3 (VDD)
VBUS: C1_BAT.1, C4_USB.1, C5_USB.1, CHG_LED.A, D1.2 (GND), D2.2 (ANODE), MCP73831.4 (VIN), PFMF.050.1.2, Q1.1 (G), R1_PWRUSB.2, TP14.TP
VRTC: C8.1, C10_SUPERCAP.2, R_CAPACITOR.2, U3.14 (VBAT)
VUSB: J2.A4, J2.A9, J2.B4, J2.B9, PFMF.050.1.1

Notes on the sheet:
USB C connector & ESD protection
LDO Voltage Regulator
SD Card
ESP32 C6
Li-Po Battery Charging Controller
E-Paper Drive Circuit
Display Type Selecto
E-Paper Display Header
EPD Power
Environmental Sensor BME688
Voltage Supervisor + Reset & Boot / IO Button
Battery ChargeLevel
RTC Module DS3231SN
Test Pads
Qwiic / Stemma QT
SPI ESD Protection Lines
External NORFlash64MB
OpenBook Schematic
drawn by: Alexandra Bulgaru

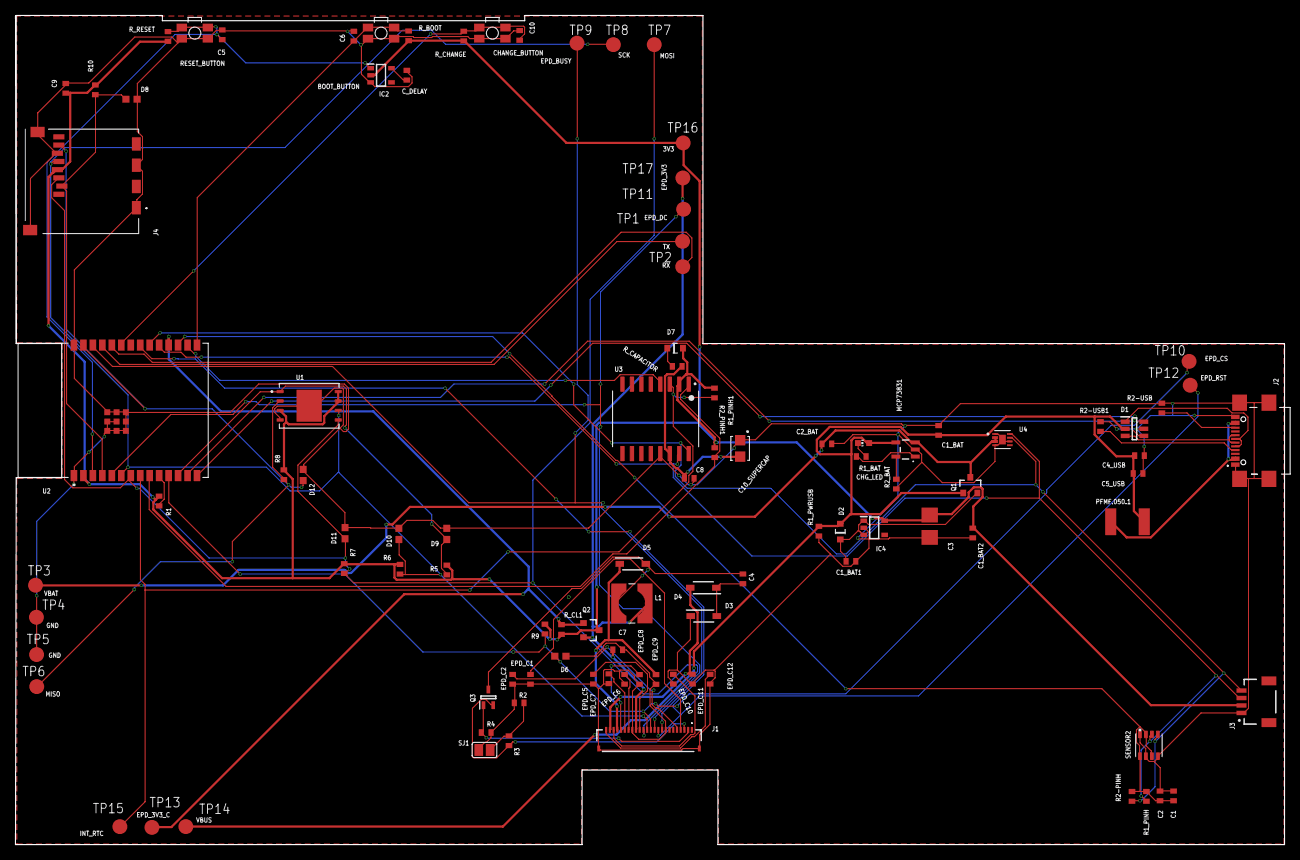
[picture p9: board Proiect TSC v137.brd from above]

Board: 2 copper layers, 170.2 x 111.2 mm, 103 parts (0 on the bottom side), 56 nets.

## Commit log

2025-04-05 project done
    [Bill of Materials.csv, Pick and Place.csv, Proiect TSC v120.brd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]
2025-04-12 bugs done
    [Bill of Materials.csv, BillOfMaterial.csv, Pick and Place.csv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]

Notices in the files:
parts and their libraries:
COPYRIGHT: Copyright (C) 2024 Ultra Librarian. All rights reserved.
